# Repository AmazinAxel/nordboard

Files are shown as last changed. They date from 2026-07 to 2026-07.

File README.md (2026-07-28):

# CH32X035 custom split keyboard

Column staggered Corne-based wired split keyboard

Main features are its single onboard CH32X035G8U6 MCU, USB-C interconnect, lowest-latency-possible yet highly portable ideology, its low cost all while being very ergonomic and comfortable!



A few things this board considers:

- Kalih Choc v1 linear switches
  - Why: for reduced key travel distance and less noise
  - Especially when using in public spaces, clicky switches are kind of obnoxious
- No battery or Bluetooth support, and a SS USB-C interconnect
  - Why: there are a lot of reasons:
  - Batteries are heavy and this would mean expanding the footprint of this design. Right now it's as minimal as it gets, adding wireless support is where things start to get bulky
  - You don't need to worry about charging or latency over bluetooth! Having cables on a desk is almost never a problem if your laptop has a spare port. This is well worth the peace of mind of having to check the keyboard battery, remembering to charge it and having to deal with connecting/disconnecting it.
  - It's the lowest latency you can possibly get. Especially for productivity, every keystroke counts and the faster something updates, the faster you can work.
  - While an audio jack DOES have just enough pins to carry data, ground and power (and is almost always the right choice for this) using a standard port with cables available everywhere allows you to use the interconnect cable for emergencies or other temporary purposes. It is highly versatile. When left in a bag, a 3.5mm headphone cable is basically useless.
  - The SS cable is necessary since it has all the necessary wires to transmit the entire right-half of the keyboard's data without needing to process it on its own half. This means we reduce cost, latency and processing cost and get to carry around a high speed cable with us fo emergencies wherever you travel.
- NOT curved, it's flat and without any key spacing (besides thumb clusters)
  - Why: This is a daily carry item. Therefore a keyboard in your backpack should be light and fit in a small front pocket.
  - Key spacing is good for keeping this compact and minimal key distance means you can fit more keys and access them faster in a smaller form factor
  - It's cheaper to produce the board
- Chocolate [Corne](https://github.com/foostan/crkbd) layout (it's very popular and its design is proven!)
- No row stagger and good column stagger
  - Why: for ergonomics, it curves better to the natural shape of your fingers and hand
  - This is inspired by Corne. Thumb clusters are modified to maximize space, though it might take some getting used to
- No LEDs or rotary encoders or OLED displays (!!)
  - Why: a big goal of this project is to be suuuper cheap. These are gimmicks and add unnecessary cost for no useful benefit. This PCB is designed to be as affordable to produce as possible
- Plateless/no hot-swap sockets
  - Why: This makes the board lighter, thinner and cheaper for carrying, and helps with assembly and keeping it low-profile
  - For me, I never need to swap my switches. I consider this a gimmick in a lot of ways since you can always desolder the switch if it breaks. There's really no reason to have it imo
- CH32X035 (CH32X035G8U6)
  - When this project was named NordBoard, it used a XIAO RP2040 which was kind of overkill since it was a devboard. When optimizing for cost (and complexity) it makes a lot more sense to just have the mcu on the board.
  - I chose a CH32X035G8U6 because its new, well-stocked, _extremely_ cheap (50 cents??) and has enough pins for scanning both sides. It is plenty fast and has USB flashing (and supports HID) and didn't require me to add additional parts for ESD protection since it's all built in.
  - It has flash and a crystal already so there's less components to place and its overall cheaper than something like an RP2040.
  - HOWEVER, the CH32X035 has terrible firmware support and no keyboard firmware supports it right now. I found some Arduino resources that can turn this chip into an HID keyboard emulator, all that's needed is to implement some matrix scanning, keyboard features like layers and then you don't need a big firmware like qmk!
  - This is what makes this board stand out. From what I can tell, this is the first keyboard that uses this new chip. It is better than its counterparts in every way. This keyboard is ahead of its curve!

The advantages of all of the above result in a very well thought-out keyboard for travel and ergonomics. I'm quite proud of the design. I hope you enjoy it too!

## Some renders






[Model available on Onshape](https://cad.onshape.com/documents/24ef5e976496ee201db7b05f/w/fbfc374ac70f5cb67c606ba5/e/005f221e2e9fc59a8e2e02ea)

## PCB & schematic





## Firmware setup

**This keyboard CANNOT run QMK or ZMK or any mainline keyboard firmware!!**

We use a very new chip which does not have support for those firmwares yet. The chip is easily programmable with Platformio and there has been work already to make it work as an HID keyboard device, so I am expanding on that to make this function as a layered keyboard.

First, you need to short the two pads on the top right of the board and plug the device into your computer through a data cable. This puts the device into boot mode so you can flash the firmware.

Clone the repo and go into the conifer/ folder. This is the custom firmware that Snowlayer runs on.

If you are running Nix, I highly recommend running `nix develop` to download deps and setup an environment for running the build.

Run `pio run -t upload`. The firmware should flash to the device, but if you are running Linux and have any issues make sure you add these udev rules:

```nix
SUBSYSTEM=="usb|tty", ATTRS{idVendor}=="1a86", ATTRS{idProduct}=="8010", GROUP:="plugdev"
SUBSYSTEM=="usb|tty", ATTRS{idVendor}=="4348", ATTRS{idProduct}=="55e0", GROUP:="plugdev"
SUBSYSTEM=="usb|tty", ATTRS{idVendor}=="1a86", ATTRS{idProduct}=="8012", GROUP:="plugdev"
SUBSYSTEM=="usb", ATTRS{idVendor}=="1a86", MODE="0666"
```

If you are not able to flash it over USB, I broke out the UART pins on the chip so that you can use a programmer and flash directly to the device. I recommend going over USB though.

Once I finish the firmware I'll attach a screenshot showing the layers and keybinds for common actions. This firmware is only partly complete.

## Bill of Materials

| Part | Where to buy | Cost before tax/shipping | Notes |
| --- | --- | --- | --- |
| Keycaps | <https://www.aliexpress.us/item/3256809223879113.html> | $20 | 50pc/1350 V1 A (Does come with 8 extras) |
| Choc Switches | <https://www.aliexpress.us/item/3256808697103313.html> | $25 | 50pc, blue (Also comes with 8 extras) |
| A short C-to-C interconnect | <https://www.aliexpress.us/item/3256811793020961.html> | $8.93 | T6A-T6B 20P, 0.25m |
| The board itself! | JLCPCB | $14.70 | 5 boards, cheapest settings (white PCB) |
| CH32X035DS0 | <https://www.lcsc.com/product-detail/C7437027.html> | $0.56 | You only need one for the whole board! |
| Switch diodes | <https://www.lcsc.com/product-detail/C917030.html> | $0.50 | 8 extras |
| 100nF capacitor | <https://www.lcsc.com/product-detail/C14663.html> | $1.27 | 49 extras, I already have these from a previous project |
| 4.7uF capacitor | <https://www.lcsc.com/product-detail/C77077.html> | $0.68 | 9 extras |
| 3x 1kO resistors | <https://www.lcsc.com/product-detail/C21190.html> | $0.30 | 97 extras, I already have these from a previous project |
| 24pin USB-C interconnect receptacles | <https://www.lcsc.com/product-image/C53207800.html> | $0.4\*2 = $0.81 | No extras |
| 12pin USB-C data receptacle | <https://www.lcsc.com/product-detail/C5178539.html> | $0.36 | 4 extras, I already have some from a previous project |
| | | **Total cost: $73.11** | Does not include tax or shipping, actual cost higher |

<!-- 20+25+8.93+14.70+0.56+0.5+1.27+0.68+0.3+0.81+0.36 -->

You will need a 3D printer & filament (I recommend blue PLA) for the case. The four mounting holes are 2.2mm radius, 3mm deep, you will need mounting screws for those. The C-C interconnect MUST be Superspeed (like the item above) or else it won't have enough lines so the right half of the board won't work right.

## For fabrication

I have supplied pre built JLCPCB gerbers in `jlcpcb`. Upload the snowlayer.zip there, select a white board, and you're done! Make sure you have all the parts from the BOM.

---

Made for [Forge](https://forge.hackclub.com/projects/827)

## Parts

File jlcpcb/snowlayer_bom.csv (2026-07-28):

Designator | Footprint | Quantity | Value | LCSC Part #
C2 | 0603 | 1 | 100nF
C5 | 0805 | 1 | 4.7uF
D1, D10, D11, D12, D13, D14, D15, D16, D17, D18, D19, D2, D20, D21, D22, D23, D24, D25, D26, D27, D28, D29, D3, D30, D31, D32, D33, D34, D35, D36, D37, D38, D39, D4, D40, D5, D50, D51, D6, D7, D8, D9 | D_SOD-123 | 42 | D
P3 | USB_C_Receptacle_HRO_TYPE-C-31-M-12 | 1 | USB_C_Plug_USB2.0
R1, R2 | 0603 | 2 | 5.1kO
R3 | 0603 | 1 | 1kO
SW1, SW10, SW11, SW12, SW13, SW14, SW15, SW16, SW17, SW18, SW19, SW2, SW20, SW21, SW22, SW23, SW24, SW25, SW26, SW27, SW28, SW29, SW3, SW30, SW31, SW32, SW33, SW34, SW35, SW36, SW37, SW38, SW39, SW4, SW40, SW5, SW50, SW51, SW6, SW7, SW8, SW9 | SW_choc_v1_1u | 42 | SW_Push
TP1, TP2, TP3, TP4 | TestPoint_Pad_D1.0mm | 4 | TestPoint
U1 | WQFN-28-1EP_4x4mm_P0.4mm_EP2.7x2.7mm | 1 | CH32X035DS0
USB1, USB2 | USB-C-SMD_TYPE-C-24P-QT | 2 | TYPEC-24PIN_C53207800 | C53207800

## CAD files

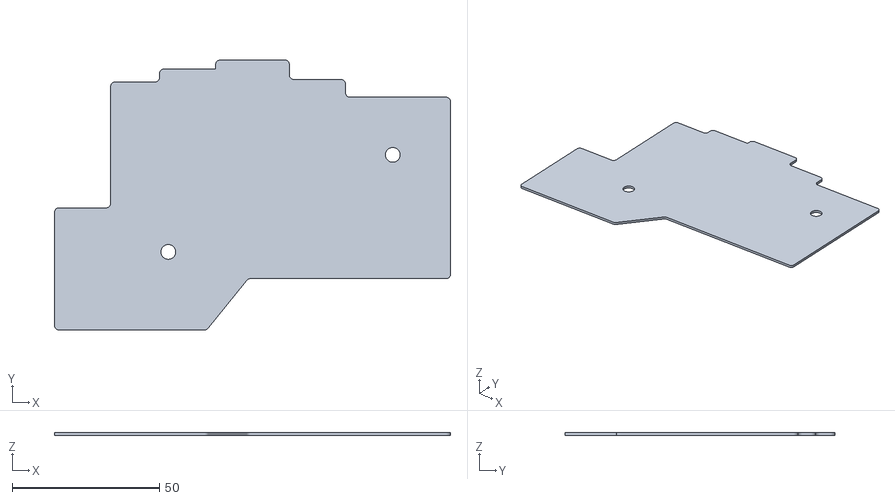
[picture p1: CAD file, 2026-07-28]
cad/Snowlayer right base v1.stl
134.4 x 91.6 x 1.00

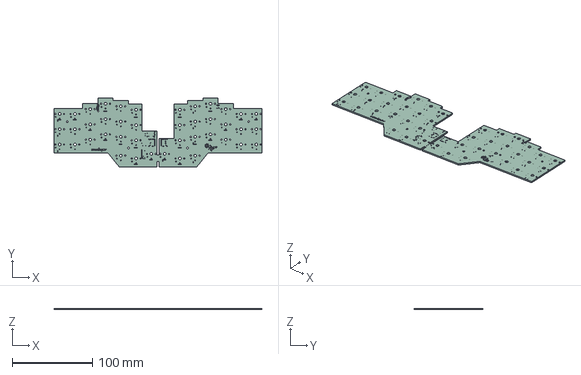
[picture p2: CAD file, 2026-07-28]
kicad/NordBoard.step
259.2 x 85.6 x 1.58 mm
snowlayer-unsaved-export-VQAgqH_silkscreen
snowlayer-unsaved-export-VQAgqH_PCB

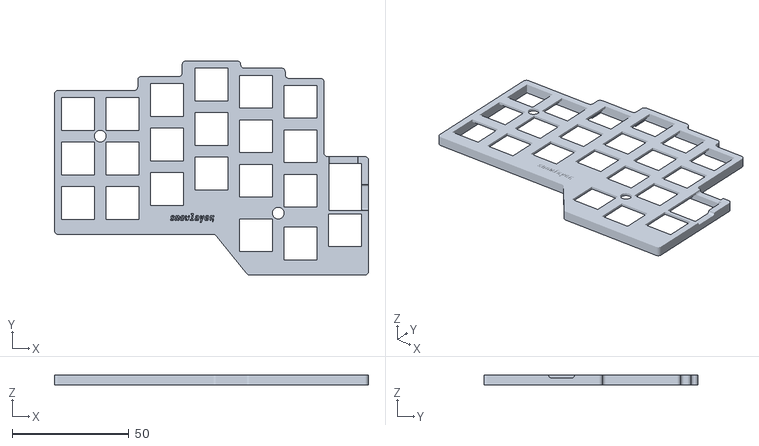
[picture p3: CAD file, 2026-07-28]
cad/Snowlayer left plate v1.stl
134.4 x 91.6 x 4.20

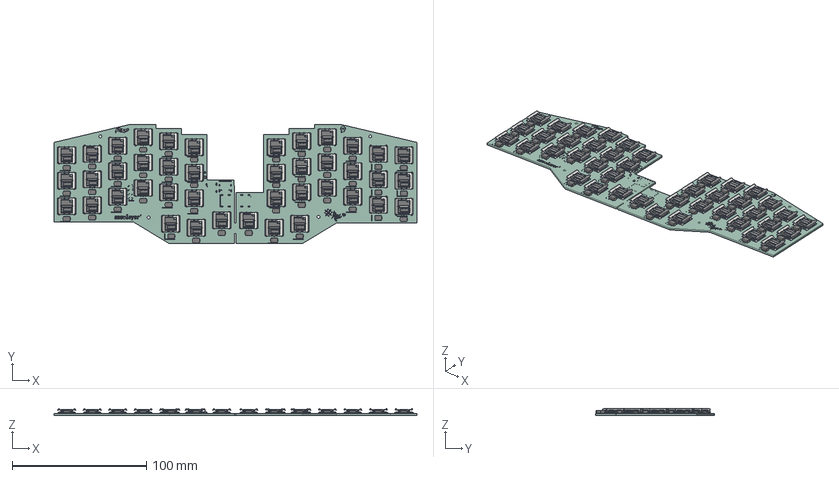
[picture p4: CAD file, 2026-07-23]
kicad/snowlayer.step
270.5 x 89.0 x 5.02 mm
lever 1 x 42
lever 2 x 42
spring x 42
pin 2 x 42
pin 1 x 42
lever 3 x 42
frame x 42
D_SMB x 42
R_0603_1608Metric x 3
C_0603_1608Metric
C_0805_2012Metric
NordBoard_silkscreen
NordBoard_PCB

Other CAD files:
cad/Snowlayer left base v1.stl
cad/Snowlayer right plate v1.stl

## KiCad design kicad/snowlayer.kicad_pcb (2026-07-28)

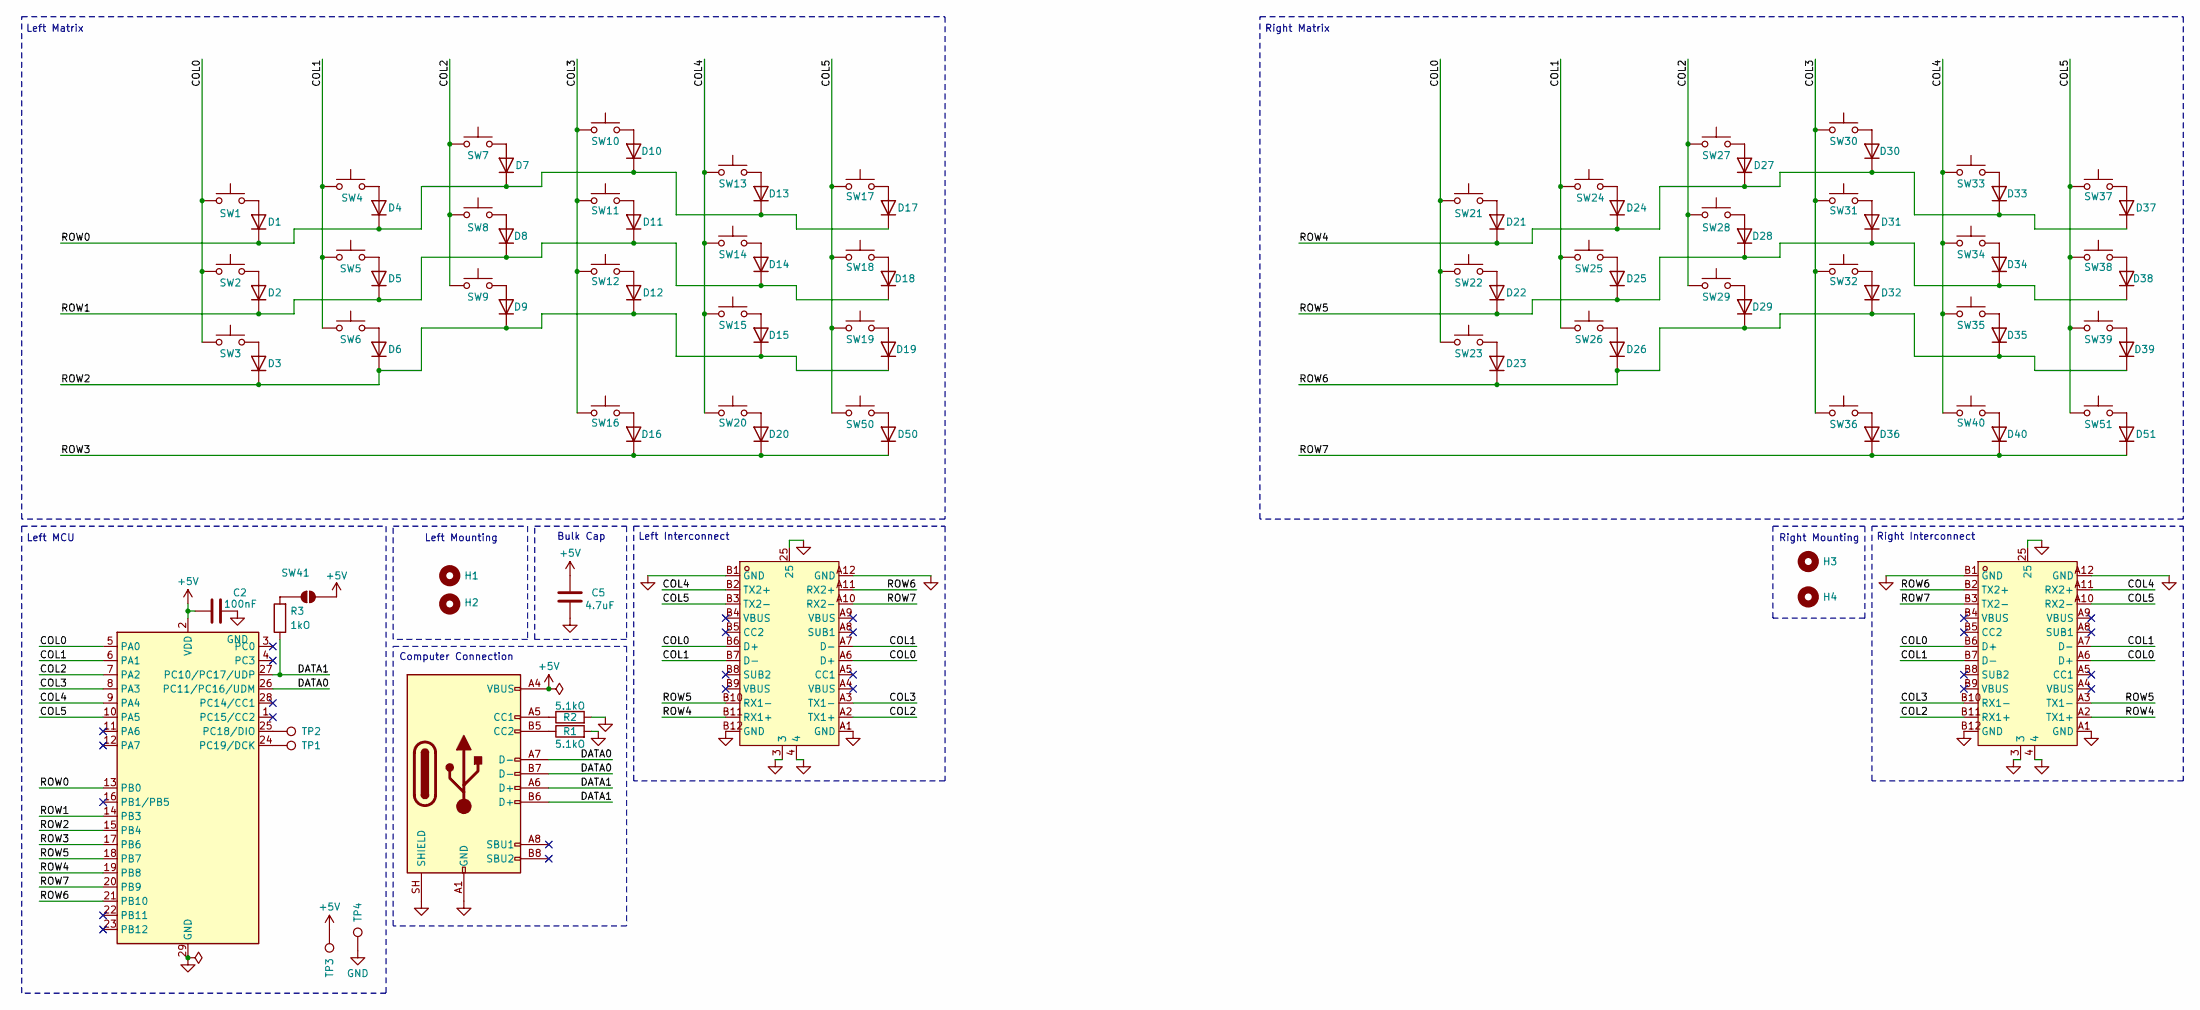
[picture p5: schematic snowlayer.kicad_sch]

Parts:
C2: 100nF; C_0603_1608Metric
C5: 4.7uF; C_0805_2012Metric
D1, D2, D3, D4, D5, D6, D7, D8, D9, D10, D11, D12, D13, D14, D15, D16, D17, D18, D19, D20, D21, D22, D23, D24, D25, D26, D27, D28, D29, D30, D31, D32, D33, D34, D35, D36, D37, D38, D39, D40, D50, D51: D; D_SOD-123
H1, H2, H3, H4: MountingHole; MountingHole_2.2mm_M2
P3: USB_C_Plug_USB2.0; USB_C_Receptacle_HRO_TYPE-C-31-M-12
R1, R2: 5.1kO; R_0603_1608Metric
R3: 1kO; R_0603_1608Metric
SW1, SW2, SW3, SW4, SW5, SW6, SW7, SW8, SW9, SW10, SW11, SW12, SW13, SW14, SW15, SW16, SW17, SW18, SW19, SW20, SW21, SW22, SW23, SW24, SW25, SW26, SW27, SW28, SW29, SW30, SW31, SW32, SW33, SW34, SW35, SW36, SW37, SW38, SW39, SW40, SW50, SW51: SW_Push; SW_choc_v1_1u
SW41: SW_Push; SolderJumper-2_P1.3mm_Open_Pad1.0x1.5mm
TP1, TP2, TP3, TP4: TestPoint; TestPoint_Pad_D1.0mm
U1: CH32X035DS0; WQFN-28-1EP_4x4mm_P0.4mm_EP2.7x2.7mm
USB1, USB2: TYPEC-24PIN_C53207800; USB-C-SMD_TYPE-C-24P-QT; MPN TYPEC-24PIN; LCSC Part C53207800

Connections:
+5V: C2.1, C5.1, P3.A4 (VBUS), P3.A9 (VBUS), P3.B4 (VBUS), P3.B9 (VBUS), SW41.2 (B), TP3.1 (1_1), U1.2 (VDD)
/COL0: SW1.1, SW2.1, SW3.1, SW21.1, SW22.1, SW23.1, U1.5 (PA0), USB1.A6 (D+), USB1.B6 (D+), USB2.A6 (D+), USB2.B6 (D+)
/COL1: SW4.1, SW5.1, SW6.1, SW24.1, SW25.1, SW26.1, U1.6 (PA1), USB1.A7 (D-), USB1.B7 (D-), USB2.A7 (D-), USB2.B7 (D-)
/COL2: SW7.1, SW8.1, SW9.1, SW27.1, SW28.1, SW29.1, U1.7 (PA2), USB1.A2 (TX1+), USB2.B11 (RX1+)
/COL3: SW10.1, SW11.1, SW12.1, SW16.1, SW30.1, SW31.1, SW32.1, SW36.1, U1.8 (PA3), USB1.A3 (TX1-), USB2.B10 (RX1-)
/COL4: SW13.1, SW14.1, SW15.1, SW20.1, SW33.1, SW34.1, SW35.1, SW40.1, U1.9 (PA4), USB1.B2 (TX2+), USB2.A11 (RX2+)
/COL5: SW17.1, SW18.1, SW19.1, SW37.1, SW38.1, SW39.1, SW50.1, SW51.1, U1.10 (PA5), USB1.B3 (TX2-), USB2.A10 (RX2-)
/DATA0: P3.A7 (D-), P3.B7 (D-), U1.26 (PC11/PC16/UDM)
/DATA1: P3.A6 (D+), P3.B6 (D+), R3.1, U1.27 (PC10/PC17/UDP)
/ROW0: D1.1 (K), D4.1 (K), D7.1 (K), D10.1 (K), D13.1 (K), D17.1 (K), U1.13 (PB0)
/ROW1: D2.1 (K), D5.1 (K), D8.1 (K), D11.1 (K), D14.1 (K), D18.1 (K), U1.14 (PB3)
/ROW2: D3.1 (K), D6.1 (K), D9.1 (K), D12.1 (K), D15.1 (K), D19.1 (K), U1.15 (PB4)
/ROW3: D16.1 (K), D20.1 (K), D50.1 (K), U1.17 (PB6)
/ROW4: D21.1 (K), D24.1 (K), D27.1 (K), D30.1 (K), D33.1 (K), D37.1 (K), U1.19 (PB8), USB1.B11 (RX1+), USB2.A2 (TX1+)
/ROW5: D22.1 (K), D25.1 (K), D28.1 (K), D31.1 (K), D34.1 (K), D38.1 (K), U1.18 (PB7), USB1.B10 (RX1-), USB2.A3 (TX1-)
/ROW6: D23.1 (K), D26.1 (K), D29.1 (K), D32.1 (K), D35.1 (K), D39.1 (K), U1.21 (PB10), USB1.A11 (RX2+), USB2.B2 (TX2+)
/ROW7: D36.1 (K), D40.1 (K), D51.1 (K), U1.20 (PB9), USB1.A10 (RX2-), USB2.B3 (TX2-)
GND: C2.2, C5.2, P3.A1 (GND), P3.A12 (GND), P3.B1 (GND), P3.B12 (GND), P3.SH (SHIELD), R1.2, R2.2, TP4.1 (1_1), U1.29 (GND), USB1.3, USB1.4, USB1.25, USB1.A1 (GND), USB1.A12 (GND), USB1.B1 (GND), USB1.B12 (GND), USB2.3, USB2.4, USB2.25, USB2.A1 (GND), USB2.A12 (GND), USB2.B1 (GND), USB2.B12 (GND)
unnamed: D1.2 (A), SW1.2
unnamed: D2.2 (A), SW2.2
unnamed: D3.2 (A), SW3.2
unnamed: D4.2 (A), SW4.2
unnamed: D5.2 (A), SW5.2
unnamed: D6.2 (A), SW6.2
unnamed: D7.2 (A), SW7.2
unnamed: D8.2 (A), SW8.2
unnamed: D9.2 (A), SW9.2
unnamed: D10.2 (A), SW10.2
unnamed: D11.2 (A), SW11.2
unnamed: D12.2 (A), SW12.2
unnamed: D13.2 (A), SW13.2
unnamed: D14.2 (A), SW14.2
unnamed: D15.2 (A), SW15.2
unnamed: D16.2 (A), SW16.2
unnamed: D17.2 (A), SW17.2
unnamed: D18.2 (A), SW18.2
unnamed: D19.2 (A), SW19.2
unnamed: D20.2 (A), SW20.2
unnamed: D21.2 (A), SW21.2
unnamed: D22.2 (A), SW22.2
unnamed: D23.2 (A), SW23.2
unnamed: D24.2 (A), SW24.2
unnamed: D25.2 (A), SW25.2
unnamed: D26.2 (A), SW26.2
unnamed: D27.2 (A), SW27.2
unnamed: D28.2 (A), SW28.2
unnamed: D29.2 (A), SW29.2
unnamed: D30.2 (A), SW30.2
unnamed: D31.2 (A), SW31.2
unnamed: D32.2 (A), SW32.2
unnamed: D33.2 (A), SW33.2
unnamed: D34.2 (A), SW34.2
unnamed: D35.2 (A), SW35.2
unnamed: D36.2 (A), SW36.2
unnamed: D37.2 (A), SW37.2
unnamed: D38.2 (A), SW38.2
unnamed: D39.2 (A), SW39.2
unnamed: D40.2 (A), SW40.2
unnamed: D50.2 (A), SW50.2
unnamed: D51.2 (A), SW51.2
unnamed: P3.A5 (CC1), R1.1
unnamed: P3.B5 (CC2), R2.1
unnamed: R3.2, SW41.1 (A)
unnamed: TP2.1 (1_1), U1.25 (PC18/DIO)
unnamed: TP1.1 (1_1), U1.24 (PC19/DCK)

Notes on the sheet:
Left Interconnect
Right Interconnect
Bulk Cap
Left Mounting
Left Matrix
Left MCU
Computer Connection
Right Matrix
Right Mounting

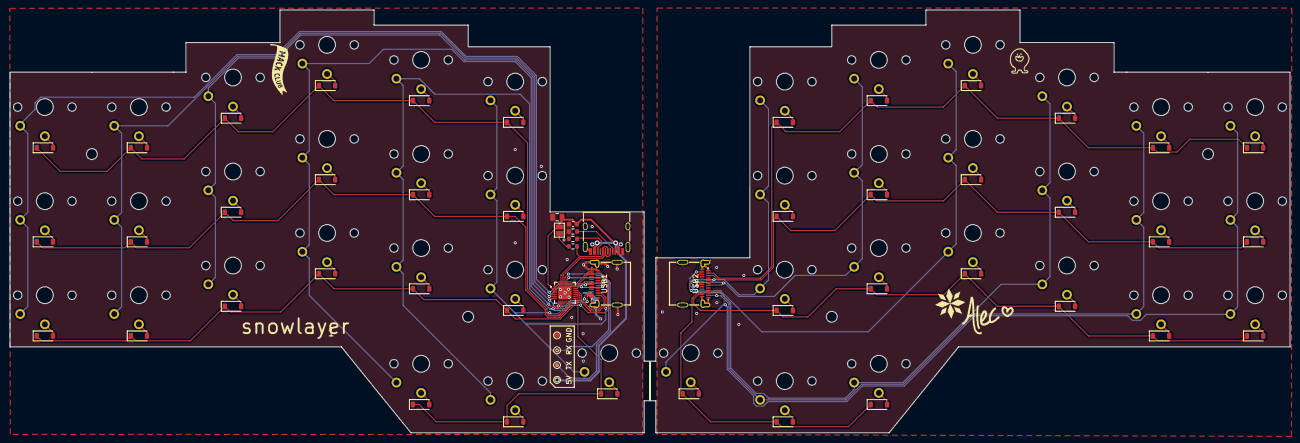
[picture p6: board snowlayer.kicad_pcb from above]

Board: 2 copper layers, 259.2 x 85.6 mm, 102 parts (0 on the bottom side), 65 nets.

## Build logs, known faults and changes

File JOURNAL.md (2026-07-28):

# 2/13/2026 - Sketched out the keyboard layout and design

_Time spent: 0.5h_

I sketched out the design of the keyboard and its layout so that I can begin making the board.

I'm planning out the most optimal and comfortable keyboard layout while keeping it as flat (diagonal) as possible. I'm not completely settled on the slope amount (I might adjust this in the future) but otherwise I'm going to design from here.







# 2/15/2026 11 AM - Began PCB & schematic

_Time spent: 1.0h_

This is my first real PCB project so I'm still new to all this. I didn't know that the schematic editor didn't actually reflect the location on the PCB :megasob:
Wasted a bunch of time getting the alignment perfect on schem instead but I did figure out how to get the proper footprints for my Choc v1 and Seeed XIAO RP2040 working.





# 2/15/2026 3 PM - Finished the schematic, PCB component placement layout

_Time spent: 3.0h_

I finished up the keyboard schematic and began working on the PCB. All components on the schematic are properly routed and accounted for. I also did an ERC check to make sure that everything was wired up properly. I imported it into the PCB editor and put all components in their place.





# 2/15/2026 10 PM - Finished tracing/routing the PCB!

_Time spent: 1.5h_

I've finished the PCB tracing. I'm pretty happy with it, so now I get to move on to the fun silkscreening stuff. I'm debating on adding another column for things like the shift key, and I might optimize the thumb cluster by rotating it slightly (we'll see!)



And look, no errors!


# 2/16/2026 6 PM - Added another column, schematic cleanup, restarted PCB

_Time spent: 3.0h_

Since I messed up the footprints for the original schem and didn't split the file properly, I had to restart the PCB again. This has given me a good opportunity to fix some issues and improve the schematic design layout. It's much more polished and properly made now.

Left (notice the proper references now!)


Right


The split keyboard tutorial is quite confusing so I also changed up the Xiao RP2040 although now I get a weird ground error when I run ERC. I also added mousebites to the main layout:


And while I still have a long ways to go, I now have the full PCB layout (minus the positioning and tracing, for which I had to restart)


# 2/16/2026 10 PM - Half of PCB completed, routed right piece

_Time spent: 2.0h_

I've finished the first half of the PCB! The second (right) part has been routed but the mounting holes or outline has not yet been placed. I think it's looking good so far!



# 2/17/2026 - Finished right PCB

_Time spent: 0.8h_

PCB layout & tracing complete. There's some DRC issues and I have to get it peer reviewed first before I send it off to JLC for fabrication. Removed 2 mounting holes since they weren't needed. I don't know whats wrong with the mousebites but I also have to get that sorted out. Silkscreen design coming soon too!



# 2/18/2026 - PCB Silkscreen, 3D model and more

_Time spent: 2.5h_

I finished the PCB. Everything is complete, from the FRC to DRC checks (no more errors!)
There's some cool silkscreen stuff now. I had to design them outside of KiCAD and import them as an SVG.


I began using Onshape to model the case for the keyboard. I'll try to keep it as minimal as possible but I haven't gotten proper 3D exports working for the key switches so I'm not sure the depth I should have for the upper solder buffer part of the case. I also wanted to implement some sort of built-in tenting solution and magnets so this can be portable, but maybe that's over-engineering it.




# 6/15/2026 - Moving to Forge and planning a redo

_Time spent: 0.5h_

This project has been imported from Blueprint. I originally started working on this project back in Feburary but I haven't had the motivation to continue it since I had a convo about having to redo much of this project due to a few oversights of mine.

I will admit that I spent much too long on this CAD model for tenting. I really don't like how it came out, so I will probably invest in my own tenting solution. I won't print this tent (probably) but I'll log it here since I did spend a lot of time on it (thats where all this time from the devlog came from. I spent multiple nights on this, fine tuning it so its actually more than half an hour of work, i'm under-counting the hours on this one since its my first entry to Forge from Blueprint and i dont want to mess anything up, you can refer to my onshape history)

a

b

With that out of the way, here's whats wrong with my current product:

- There is no interconnect cable, instead I relied on two usb-c cables for data. Apparently this will break cross-keyboard communication and I wont be able to use mod keys from the left on the right of the keyboard. This is a dealbreaker for me so I am adding an interconnect cable (which will be done in the next devlog)
- The current 3d model relies on a PCB that will be a different shape to support the cable. I'll have to redo it, and honestly I might just go for a borderless exposed PCB design because it will be lighter and smaller and I want this to be very portable
- There is a big issue with it being basically the same schematic duplicated twice, and since i will have to make a new schematic for the right side it'll basically be a complete PCB rewiring and everything. this is gonna be so painful :sob:
- The project is suuper poorly organized right now, there are tons of library stuff and dependencies in my literal Downloads folder. I don't really know how this happened but I cant work on the project on my other computer since the Kicad deps dont exist. I'll have to figure out how to fix that, not sure how yet

There are a bunch of issues and it's gonna be really painful to have to redo basically this whole project. That being said, I don't anticipate to work on this every day so my forge streak is basically cooked. See ya in the next devlog!

# 6/16/2026 - Redoing basically everything (part one!! yay)

Time spent: 1.2h

Spent much of the afternoon/night on this. So after installing a Nord theme I have basically started redoing everything, starting with having everything in one sheet to make it easier to wire up the interconnect. This is what it looked like before:







And after: (you'll notice its in one sheet now and there's an extra switch!)



Also, remember how I basically hardlinked the entire thing to my Downloads folder instead of bundling it in the project? Look who gets to deal with this mess:



So now it's just a matter of actually doing the interconnect cable. Seeing that the annotations have changed with the new switch placements, I still think the whole PCB will have to be retraced.

# 6/24/2026 - Redoing everything (part two!!!)

Time spent: 5h

Been working on this for a while. Very very happy to report that I have finally managed to reorganize and clean up this project enough that I can now work on it on another computer. So for context: I had hardcoded all of the paths for the libraries and symbols and everything to my _Downloads_ folder. Anyone who cloned my project would've encountered numerous errors, but now that's a thing of the past. I successfully managed to get all of the paths softcoded to the project library, so there shouldn't be any more issues.

This is what the checks look like now (no more errors!! and everything is vendored in the project!)





(those aren't DRC checks though, those are footprint and symbol updates, which fetch from the libraries! I also took this opportunity to clean up and massively reduced the libraries this depends on by only importing what is needed.)

So I also did some reorganizing of the PCB. I updated the edge cuts to be slimmer and fit more with the additional thumb cluster button (yes that's right - there are 3 thumb clusters now!)



I also completely redid the schematic now. I reordered the buttons on both sides and fixed a major issue with it being connected to the wrong rows, which would've made the button double press. I attempted to do an interconnect with just a USB-C port on the left and the Xiao on the right but I guess that's not possible, so I've started working on adding USB-C ports for interconnect on both sides.





Anyways, as you can see, I have been quite productive even with the major setback. I plan on getting the interconnect wired up, then I'll improve some of the edge cuts and work on the plates and case. Until next time!

# 6/25/2026 - Finishing the new schematic and interconnect

Time spent: 2.5h

I've been hard at work yesterday evening and this morning getting the schematic finished up. I have had a lot of discussion about whether I can connect the left interconnect directly to the Xiao on the right, but unfortunately that does not seem to be possible and I'll just have to live with an unused USB-C port on the right sadly. I can't even use it for something like type-C charging or as an extra data port, so we're basically just wasting an entire receptacle. There are a few good things that came out of this. The first is that with a USB-C interconnect, that means that it's a removable C-to-C cable I can use for other devices in an emergency (when traveling). The other is that this will allow me to have the two boards communicate with each other for more key combos. And it also reduces the total cable clutter since I won't have another cable plugged into my computer. There is also space in the PCB for me to add the USB receptacles without causing too large of a redesign.

I pondered whether I would want to add Bluetooth and a battery to this board. After realizing that I literally just used up the very last pin on my Xiao (I maxed this thing out pin-wise, I think that's pretty cool) I realized that this would have been too much of an undertaking and I'll leave that for a v2.





There are a few issues with the schematic import into the PCB. The most obvious is the wackiness with the new switches, I don't even know why they are there since the new ones should've replaced them. I'll figure that out later today and hopefully get the PCB finalized so I can work on the case and plates.



# 6/25/2026 - THE PCB IS DONE

Time spent: 5.5h

oh my god this is insane. I have spent the ENTIRE evening working on this and I feel very accomplished. For starters, basically I redid the entire board in some capacity. Edge cuts, placements and basically the entire PCB routing has been redone for interconnect performance and stability. Now I have to start worrying about interference and wider trace widths for large power. I think honestly it's just easier to look at the board and see how different it is:

wow

Starting with the schematic, I spent hours fiddling with the USB-C ports in the PCB because the 0.5mm 5v lines were too thick and there was a total mess of wires clogging up that area. So I decided to relabel the left Xiao to prioritize wires that go to the left so that there'd be no interference with wires that go down. After doing so, I went from a mess of wires with the resistor and the Xiao and USB-C receptacle to THIS:

also wow

I know I don't have a comparison image for this but you can take my word for it that this thing is pretty well optimized for both space and speed. Did I mention that the USB-C port trace is as close together as possible to reduce right-side latency? Also, the big blue fill you see is me figuring out how ground fills work, since apparently these help reduce noise for things like this. I had a lot of issues with it messing with the DRC so I fixed those issues and now I have a perfect score!



Basically I touched up on every single trace on the board to optimize & clean it up. (I also learned that KiCAD has a few built-in tools to clean up the PCB, this would've been nice to know sooner!)

Anyways the PCB is fully completed now. Everything is in order for me to start modeling the plates and cases!! I think that I spent a little too much time on this devlog since the last journal, I might try doing a Lapse next time when I am using Onshape for modeling.

## 6/26/2026 - Modeling is almost done!

Time spent: 6.5h

It's time for me to submit this project! A lot has happened today. For starters, the case is now 100% complete. I spent literally three hours on this simple case because Onshape is annoying and slow when it's dealing with huge composite parts like this PCB. Here's what it looks like!






If you have a keen eye, you might have noticed that there were several board revisions since my last journal entry. After putting this case together, I realized that the screw holes have to be close to the edge of the board without any solder obstructions so that they're stable. I realized that the mounting holes near the USB-C ports would actually destabilize the structure, so I decided that I won't include those and revised both the board and the schematic to remove those. This means that yes, there is only two mounting holes but they are strategically located so lifting up on the board should not seperate it from the case. (also updated my signature a little bit, I think it looks nicer :D)

For anyone interested, this is what the final schematic and PCB looks like after all the revisions and trace routing updates:




I also managed to get 3D models working for all components in KiCAD so I could do full renders like what you see above.




This actually took a lot of work hunting down 3D models that would work for all the footprints. I think the models look great! Also it really helps to have the actual components on the board for taking renders. Sadly Onshape's support for importing models is pretty lame and slow and took me ages to get imported for rendering and building.

I rewrote the README. It has a lot more information now. After pondering and researching whether I should include a plate with this build, I realized that I actually don't need one and my original intent for including these models was kind of unnecessary. So for right now, I won't be modeling a plate and we'll be sticking with a bare PCB for right now. From my research, as long as there are 5 pins for each switch, it is stable enough and because it is low-profile, there is little to no advantage other than sound dampening and maybe some protection. I did attempt to model a plate though, but that was kind of wasted effort since I realized with how close together these keys are there is very little room for the plate to wedge by the diodes and switches (this board is VERY compact and optimized).

I put the gerbers into JLC and it's pretty cheap. I did optimize for cost, and I was very pleased to see that choosing a white PCB does not increase cost (this is great for the overall final build design)



(also there is like $30 shipping which is pretty bad. I accounted for that in the BOM, hopefully it'll actually cost less when I enter my address, we'll see)

The very last thing remaining is writing up the firmware. I'll have to figure out how to get the interconnect part over USB-C working with the firmware and then make some key layers. I have finished up the BOM and the README so I'm almost at the finish line!

## 6/26/2026 - The firmware is done! Project complete!!

Time spent: 0.1h

I did a LOT of research of the different firmwares I could use for this. In the end, I decided on QMK because it can be the lightest and fastest for this chip. I didn't like ZMK because it's basically just for Bluetooth/battery keyboards and would not work well with my board that lacks wireless capabilities. KMK was also another option, however I don't think it's very lightweight (it runs Python...) and I feel like C, as a lower-level language, would provide better resource management, energy usage and lower latency.

I spent a few hours tinkering with the firmware to get it to build. I followed the docs to get it all set up on NixOS (which was a little more difficult than something like Debian, but it does seem like there is good unofficial support) and I struggled with the fact that QMK does not like projects stored outside of its config directory. I was able to symlink the folder from my Github project into my home and the builds worked pretty well. I am still a little confused with all the files in the firmware folder, I don't know why it can't just entirely be a JSON file. Anyways, I used a template setup for a Corne keyboard and it compiles! Unfortunately I don't have another keyboard to test it on, so I'll have to wait until I can build the keyboard before I can iterate on this firmware. But it is finished!



(note that I set the time spent here to 0.1 hours but I actually spent 3-4 hours on this. I think Hackatime tracked this well enough so I won't include any hours in this journal. Hackatime project name: NordBoard)

Seeing as the case, PCB, and firmware are all complete, this project is DONE. I'm sending it off for design review now!

## 07/08/2026 - Saving costs

Time spent: 0.15h

So my little brother showed me a trick which both simplifies my schematic and reduces fabrication cost! Instead of using mousebites, I've instead replaced them with a few indented areas and a silkscreen to show what needs to be dremmeled. Since I will have to dremmel the board, it'll save on printing fees since it won't be paneled as according to JLCPCB (and I won't be charged as such). Other than reducing cost, I have fixed a few issues with the ground plane for the USB-C receptacles so now it'll function better. Specifically, the ground plane islands weren't connecting to the primary plane so I used my (only) vias (with larger traces) to connect them together and reduce the area for ground to travel through. Also the wiring was kind of messy for the top level ground connections so I improved those too with wider traces.



I also rewired a lot of this area to reduce wasted space from the USB-C port and made it match evenly with the left side.



Here are the updated schematic and PCB pictures:





## 07/21/2026 - Taking a new approach

Time spent: 2h

I've reviewed the feedback that Cyao gave me and I still want to keep this as a T2, so I will be moving away from a XIAO RP2040 and will instead be soldering a STM32F042K6T6 to the board. I am removing the right side's MCU and instead will be using a massive nonreversible interconnect cable to connect both boards together.

Left side with the unfinished MCU and interconnect:



Right side with the unfinished interconnect and the MCU removed:



The USB-C interconnects have been upgraded to support more pins, as you can see.

I spent a lot of time researching the best approach for this setup. I found out that with this approach, it's much cheaper and I'll save on component costs and energy usage since the STM32 is more efficient for this board. It is also well supported by QMK but I will have to rewrite the firmware to make it think that the board is not split. Also - I had looked around to find a new interconnect cable that would be capable of supporting all the interconnect pins. This looks the most promising (and cheapest) so I'll add this to the BOM:




## 07/21/2026 - Finding a great new MCU, wiring most of it up

Time spent: 3h

So I went with a STM32 originally, but I wasn't happy about it. Look at this mess, there's so much I needed to do for it to safely work (all these components!!):



The STM32 chip I chose was over a decade old, not in stock in LCSC, super expensive (like $4 for a small underpowered outdated chip? Really?) and honestly it felt like it shouldn't even be recommended for new designs. I did a LOT of digging. Trust me, hours spent on finding the right MCU and researching how to use them (yet I am not counting them, I'm only counting hours making the schematic). I compared a bunch of these together and I really want to make something I can share with others at the lowest possible price. I found a line of products called the CH32 and they have zero QMK support. Yet, they are super cheap and it would work great for a keyboard! The thing is, there is not much documentation since it is a really new MCU but I'm willing to spend the time to get it working with my own firmware not based on QMK. I found an Arduino library that I can use for using it as an HID emulator, and I would just need to implement the matrix scanning and layers to have it work as a fully functioning keyboard.



I wired up the interconnect USB-C ports. This was really hard since I can't get this wrong. It has to run all of the wires (meaning all the columns and rows that the right side has) through that fat cable and because of how USB-C is designed, it flip flops RX/TX and I have to account for that.





Anyways this entire project has been a rollercoaster. I'm hoping that after this, I get a good opportunity to trim down the keyboard some more since it'll be smaller and even cheaper (we are going from two Xiaos ($20) to a MCU that costs just 56 cents on LCSC). In the next journal, I should have the schematic complete!

Side note: I plan on renaming this project soon. I don't know what yet, but seeing as this is a more technically complex project than I had anticipated, it feels fitting to rename it for the new v2 design that I'm going for here with the new MCU. I dont know, I'll keep thinking about it.

# 7/21/2026 - Finishing up the new schematic

Time spent: 1.5h

The schematic is DONE!!! Now I can finally work on the PCB (which honestly is the most fun part). Had a lot of struggles with DRC/ERC errors because of all the footprints, and I was able to massively reduce the amount of waste and diodes and capacitors as compared to the STM32 design. It is now very efficient and cheap and should work great!





Next journal should be me finishing up the PCB. It's gona be quite difficult since the components are so small. I'm going to save a LOT of space without these Xiaos! (this does mean that I'll have to rework my CAD model and firmware, though)

# 7/22/2026 - PCB work, and realizing that I messed up

Time spent: 2.5h

I've been hard at work on the PCB. It's been very difficult (as compared to the last iteration) because these USB-C ports are so tiny. This is the first time that I've had to use vias to route around these small areas, and I kind of went crazy with it. Honestly this has been a huge undertaking since I basically had to redo half the board since most of the lines were around the XIAO which got moved down to the board. I'm trying out a few names like Snowdrift for the board, I'm not sure I will settle on that yet.







I realized I made a huge mistake. First thing is that the MCU is way too far away from USB-C. Like I don't even know what I was thinking making it so far away like that, it's gonna add so much latency. So I'm going to redo that. However, the right side of the board is fully complete over USB-C and I haven't yet finished the wiring for all the capacitors and pulldowns yet, so I don't think this is a major issue. I am going to have to add a lot more space on the part of the PCB where the Xiao's were so I'm not particularly happy about that (since it makes it even more asymmetrical) but hopefully it will function better that way. Anyways, not going so good... hopefully the next devlog will be better.

## 7/22/2026 - Finishing the PCB!! Yay!!

Time spent: 4h

OK spent the ENTIRE day on this. I feel really happy now.

I realized a few times that I needed to move components around. The most major of these times was realizing I had placed the USB-C port 1mm too far up so I moved it down a millimeter. This is before:



And this is after:



That took a lot more time than it looked. Also, I had made a few schematic changes.



From the above, you can see that I've moved away from using a button and instead I'm using a switch with the footprint of two test pads. This is cheaper, slimmer (so I can fit it into the side profile of the new board, between the key and the board's edge, just under the keycaps near the USB-C port so it has easy access) and fits a lot more with the ideology of this board.

I am renaming this project to Snowlayer. I am going to update the Github URLs but I don't think I can rename this Forge project.

THe most difficult part of the routing was my tendency to redo everything after realizing I can move components closer together. I also had a lot of difficulty with the USB-C ports since they were so jam packed together! And the MCU had much less spacing than I had with the XIAO. I'm glad I made this change - it does a lot to my end goal of reducing costs, increasing efficiency and reducing waste, although it will take a lot more of my time as I figure out a firmware.

Here's the DRC for anyone interested. I managed to fix everything, but I did have to adjust some settings because of the USB-C port restrictions, so I'm not really happy about that (it shouldn't affect JLCPCB price though and I think electrically it's fine)



The reason for the unconnected parts is because they are supposed to be connected together (they are linked in the schematic) but I am running a USB-C cable between them so that's the thing thats actually transferring the signals. So it will work, but I had to silence those DRC errors.

Another big change is that I switched to a dual ground plane pour, so now the top layer has a pour connected with a few stitchings that I placed around the USB-C ports. It actually looks cooler this way. Here is the 3D views!





Unfortunately, PCB price didn't change much. Didn't expect it to, but its still pretty cheap for what it is.



Thats it for this journal entry. Hopefully it's going to be the second-to-last as I finish up the base firmware and the new 3D CAD model. Maybe I'll even get it done tonight?? We'll see..

## 7/23/2026 - Finishing snowlayer up (again)

Time spent: 2h

The hard part's out of the way. I imported the model back into Onshape and rebuilt the case. I took a few renders and polished up the readme once again.

I used Platformio to make a quick firmware for the board. I can't test it, but it should work in a basic sense and I will finish it once I assemble the board. I put some flashing instructions in the readme as well!

I went through LCSC and found everything I'd need for the BOM. Everything's in there, including the stuff I already have. I removed the shipping from the price list and it's now sub-$100 when not taking into account taxes and shipping. A sub $100 split is pretty good IMO.

I changed out a few footprints to use cheaper components. The diodes were the big thing. I found a much cheaper diode and it required a different footprint, which required me to rewire the entire diode part of the keyboard.





It might not be that visible in the screenshot but all of the red wires connecting the diodes and switches had to be redone to support a smaller footprint. I'm also really mad at myself right now after I realized that I can move the diodes to be inline under the keycaps, meaning I can actually make the board _smaller_ which saves even more on costs, spacing and increases portability. Since I'm done (again) I'm going to resubmit and fix up the diodes later before I build it.

I also had my little brother review my PCB again. It can be improved, I might ask some other people in #electronics to see if they can help me out. Most important thing is getting the USB-C data port working, that's probably where I will have the most issues.

## 7/23/2026 - Rerouting once more...

Time spent: 1h

Well, being a perfectionist isn't always easy...

I'm rerouting the entire board once more. This time, I am learning from my mistakes and I'm going to have this be my _final_ revision (hopefully..) so I'm going to slow down a bit. I'll see if i can get Lapse set up, since i think its back online, and then I'll try recording my screen to see if that works better than having to rely on a clock for tracking my wiring hours.

Anyways, i'm doing the _opposite_ of pricemaxxing and making the board literally as small as it gets. There is almost nothing I can do to make it smaller than this, other than removing a few keys which i just cannot do if I want to stay productive. I literally moved every single component on the board and I am going to be redesigning the case to support proper edges. This is what it now looks like, WITHOUT the new routing and still with the wires for layout (since it is now pixel-perfect):



I'm going to keep this one short as there really isn't much else to say. Gonna have to move all of the diodes back to where they were though, that's gonna be even more painful.

## 7/24/2026 -

Time spent: 1.2h

It's fun seeing what you can change to fix two problems at once.

After talking a bit in [#electronics](https://hackclub.slack.com/archives/C056AMWSFKJ/p1784867138268339) to see what i can do, I found a few ways to improve my board. Like I said in my last post, I'm starting from scratch again and I think _this_ time will be it. There's so many things I've changed and learned throughout this project, and I'm not going to settle for something jank like what I had originally.



I repositioned everything, by hand. Basically all of the alignments of the key switches were off, and I moved them all by hand and centered each of the diodes so that they're pixel perfect. As part of this, I'm wiping the entire wiring of the board. There is a lot to be said about this project - its something that can only end when I have found nothing else to optimize or fix.

The biggest change to this project is the new USB-C interconnect. it's a much cheaper component (only 40 cents!) and its footprint allows me to wire things underneath it, which is HUGE for space saving and reducing the mess of wires that I have.



The above component change means we can reduce the size of the board even further since I can route under the USB-C port. And it saves us more money! However this took a lot of time - I had to learn how to use easyeda2kicad (which was actually really easy on NixOS, had to get around some weird upstream bug though) and change all the pins to Passive to fix some ERC warnings. Was quite painful, but otherwise the schematic is a lot cleaner now!





At this point, I don't think there is anything else here that I can optimize for cost... I'm going to lapse myself completing the traces and then it's done!

## 7/26/2026 - Finishing the layout

Time spent: 1h

OK I'm going to be honest - I spent two days on this and I'm tracking 1hr because I think I'm taking this a bit too far. I have been meticulously moving the silkscreen edges so that they are perfectly aligned on both sides. Everything is perfectly aligned now (as best I can anyways) and I am happy with the result. HOWEVER, I did not do any routing because I moved basically everything around. For starters, the furthest edge keys have been aligned so that they are the same y-level. The cuts have been optimized to the micro-millimeter and the cost is down by another dollar.

This is what it finally looks like in 3D, minus the new routing:



Here's what the pcb looks like now:



And this is what the new outlines look like now (I spent way too much time on this)



So yeah, no new routing progress. Just thought that I would share what the new design looks like before I finish the routing part. And about Lapse, I tried to get that working but I unfortunately couldn't get that working in my browser and Lookout doesn't work with forge so I'm just going to do it like I am with these journals for now.

Also - other than completely repositioning the layout, I also repositioned each of the keys and checked them on both sides so that they match perfectly! I did a little more research about the Cheapuino boards and I think there is room for cost improvement here, but I think I will leave that to a v2. Anyways, super happy with how things are right now and I am excited to start routing once more!

# 7/27/2026 - Finished!!!

Time spent: 0h

And... it's done!! (again)

So this time I figured out how to use Lapse. I realized the whole time that it _was_ working but I wasn't waiting long enough for a new snapshot to be taken, I just thought it would record at a normal 60fps but it only takes a screenshot every minute, so that confused me... anyways, I lapsed EVERYTHING in this devlog!! Yay!!

Here are my lapses, I hooked it up to hackatime as well:

<https://lapse.hackclub.com/timelapse/3SJWrnRTiUxC>

<https://lapse.hackclub.com/timelapse/YeEumRzy1A_l>

<https://lapse.hackclub.com/timelapse/cq0qLvTQu5AG>

Since I feel like the lapses explained basically everything I did, I don't think this will be a very long devlog. (also I'm marking this as 0 hours since lapse recorded EVERYTHING)

So what does the final product look like? THIS:





And the case:









And that's it!

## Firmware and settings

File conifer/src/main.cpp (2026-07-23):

#include <Arduino.h>
#include <USBHIDKeyboard.h>

// todo
static const uint8_t ROW_PINS[] = { PA0, PA1 };
static const uint8_t COL_PINS[] = { PA2, PA3 };

#define NUM_ROWS (sizeof(ROW_PINS) / sizeof(ROW_PINS[0]))
#define NUM_COLS (sizeof(COL_PINS) / sizeof(COL_PINS[0]))

static const uint8_t KEYMAP[NUM_ROWS][NUM_COLS] = {
  { 'a', 'b' },
  { 'c', KEY_RETURN },
};

// Debounce: number of consecutive identical scans before a change is accepted.
static const uint8_t DEBOUNCE_SCANS = 5;

// ---------------------------------------------------------------------------
static bool    keyDown[NUM_ROWS][NUM_COLS];   // current stable state
static uint8_t stableCount[NUM_ROWS][NUM_COLS];
static bool    lastRead[NUM_ROWS][NUM_COLS];

void setup() {
  for (uint8_t r = 0; r < NUM_ROWS; r++) {
    pinMode(ROW_PINS[r], OUTPUT);
    digitalWrite(ROW_PINS[r], HIGH);          // inactive (not selected)
  }
  for (uint8_t c = 0; c < NUM_COLS; c++) {
    pinMode(COL_PINS[c], INPUT_PULLUP);
  }

  for (uint8_t r = 0; r < NUM_ROWS; r++)
    for (uint8_t c = 0; c < NUM_COLS; c++) {
      keyDown[r][c] = lastRead[r][c] = false;
      stableCount[r][c] = 0;
    }

  Keyboard.begin();
  delay(1000);                                // let the host enumerate
}

void loop() {
  for (uint8_t r = 0; r < NUM_ROWS; r++) {
    digitalWrite(ROW_PINS[r], LOW);           // select this row
    delayMicroseconds(5);                     // let the line settle

    for (uint8_t c = 0; c < NUM_COLS; c++) {
      bool pressed = (digitalRead(COL_PINS[c]) == LOW);

      if (pressed == lastRead[r][c]) {
        if (stableCount[r][c] < DEBOUNCE_SCANS) stableCount[r][c]++;
      } else {
        stableCount[r][c] = 0;
        lastRead[r][c] = pressed;
      }

      // Commit a change only once it has been stable long enough.
      if (stableCount[r][c] >= DEBOUNCE_SCANS && keyDown[r][c] != pressed) {
        keyDown[r][c] = pressed;
        uint8_t k = KEYMAP[r][c];
        if (k) {
          if (pressed) Keyboard.press(k);
          else         Keyboard.release(k);
        }
      }
    }

    digitalWrite(ROW_PINS[r], HIGH);          // deselect
  }
}

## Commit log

2026-02-14 feat: readme & begin project
    [BOM.csv, NordBoard.kicad_sch]
2026-02-15 feat: PCB
    [NordBoard.kicad_pcb, NordBoard.kicad_sch]
2026-02-15 feat: work on schem layout
    [NordBoard.kicad_sch]
2026-02-15 feat: schem
    [NordBoard.kicad_sch, leftMatrix.kicad_sch, leftXiao.kicad_sch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]
2026-02-15 feat: finish schem, finish PCB layout
    [NordBoard.kicad_pcb, side.kicad_sch]
2026-02-16 chore: cleanup
    [leftMatrix.kicad_sch, leftXiao.kicad_sch, xiao.kicad_sch]
2026-02-16 feat: finish pcb layout and cleanup todo routing
    [NordBoard.kicad_pcb, NordBoard.kicad_sch, side.kicad_sch]
2026-02-16 feat: finish board routing
    [NordBoard.kicad_pcb]
2026-02-16 feat: new col in schem (not in PCB)
    [NordBoard.kicad_pcb, side.kicad_sch]
2026-02-16 feat: revamp schem
    [BOM.csv, NordBoard.kicad_pcb, side.kicad_sch]
2026-02-18 feat(v1): finish PCB layout
    [NordBoard.kicad_pcb]
2026-02-18 chore: pcb board cleanup
    [NordBoard.kicad_pcb, side.kicad_sch]
2026-02-18 feat: implement mousebites
    [NordBoard.kicad_pcb, NordBoard.kicad_sch]
2026-02-18 feat: finish PCB awaiting peer review + silkscreen
    [NordBoard.kicad_pcb, NordBoard.kicad_sch]
2026-02-19 feat: finish PCB silkscreen, export STEP
    [NordBoard.kicad_pcb, NordBoard.step]
2026-02-19 fix: fix pcb errors
    [NordBoard.kicad_pcb, side.kicad_sch]
2026-06-16 feat: add JOURNAL.md
    [BOM-NordBoard.csv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]
2026-06-17 journal and some work
    [NordBoard.kicad_pcb, NordBoard.kicad_sch, right.kicad_sch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]
2026-06-24 major feat: completely restructure project, new switches, no more path hardcoding
    [BOM-NordBoard.csv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]
2026-06-25 feat: new journal, fix some errors, usb-c interconnect, new edge cuts and so much more
    [NordBoard.kicad_pcb, NordBoard.kicad_sch]
2026-06-25 feat: interconnect cable, new journal
    [NordBoard.kicad_pcb, NordBoard.kicad_sch]
2026-06-26 feat: new journal, finish PCB
    [NordBoard.kicad_pcb, NordBoard.kicad_sch]
2026-06-26 feat: switch to 5.1k resistor, fix all 3D models
    [BOM.csv, NordBoard.kicad_pcb, NordBoard.kicad_sch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]
2026-06-26 chore: impove traces, cleanup
    [NordBoard.kicad_pcb]
2026-06-26 fix: update pcb traces
2026-06-27 feat: gerbers, new journal, update readme, finish BOM
    [BOM.csv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]
2026-06-27 feat: firmware, final journal entry, remove gerbers, cleanup schematic
    [NordBoard-B_Cu.gbr, NordBoard-B_Mask.gbr, NordBoard-B_Paste.gbr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]
2026-06-28 chore: update readme, add C-to-C interconnect to BOM
    [BOM.csv]
2026-07-08 feat: switch away from mousebites to reduce cost
    [NordBoard.kicad_pcb, NordBoard.kicad_sch]
2026-07-08 chore: sync before reroute
    [NordBoard.kicad_pcb]
2026-07-08 feat: improve traces, add jlcpcb export, new journal
    [NordBoard.kicad_pcb, NordBoard_bom.csv, NordBoard_designators.csv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]
2026-07-13 feat: fix ground plane overflowing into dremmel area, better font
    [NordBoard.kicad_pcb]
2026-07-21 feat: new journal, switch to new interconnect and MCU
    [NordBoard.kicad_sch]
2026-07-22 feat: switch to new MCU, new journal
    [NordBoard.kicad_sch, SOT23.step]
2026-07-22 feat: finish schematic, new journal entry
    [NordBoard.kicad_pcb, NordBoard.kicad_sch]
2026-07-22 feat: new journal, more routing
    [NordBoard.kicad_pcb]
2026-07-23 feat: alomst finish new PCB routing
    [NordBoard.kicad_pcb, NordBoard.kicad_sch]
2026-07-23 feat: new journal, rename project, finish PCB
    [NordBoard.kicad_pcb, NordBoard.kicad_sch, snowlayer_bom.csv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]
2026-07-23 feat: new cad model, update readme
    [NordBoard.step]
2026-07-23 feat: major reorg, update readme
    [BOM-NordBoard.csv, BOM.csv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]
2026-07-23 feat: add jlcpcb output
    [snowlayer_bom.csv, snowlayer_designators.csv, snowlayer_positions.csv]
2026-07-23 feat: finish BOM, change out diodes + major rerouting, new journal entry
    [snowlayer.kicad_pcb, snowlayer.kicad_sch, snowlayer_bom.csv]
2026-07-23 chore: update BOM
2026-07-24 feat: new journal, redo board outline
    [snowlayer.kicad_pcb]
2026-07-24 feat: sync routing and new pcb design
    [snowlayer.kicad_pcb]
2026-07-24 feat: new journal, better components
    [snowlayer.kicad_pcb, snowlayer.kicad_sch]
2026-07-25 chore: upd readme
    [snowlayer.kicad_pcb]
2026-07-26 feat: new journal, finish layout
    [snowlayer.kicad_pcb, snowlayer_bom.csv, snowlayer_designators.csv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]
2026-07-28 feat: new journal, update all file outputs, finish routing/case
    [NordBoard.step, Snowlayer left base v1.stl, Snowlayer left plate v1.stl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]
